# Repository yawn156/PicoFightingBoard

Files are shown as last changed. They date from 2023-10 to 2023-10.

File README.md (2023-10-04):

# Pico Fighting Board

Small fork of the OG Pico Fighting Board.

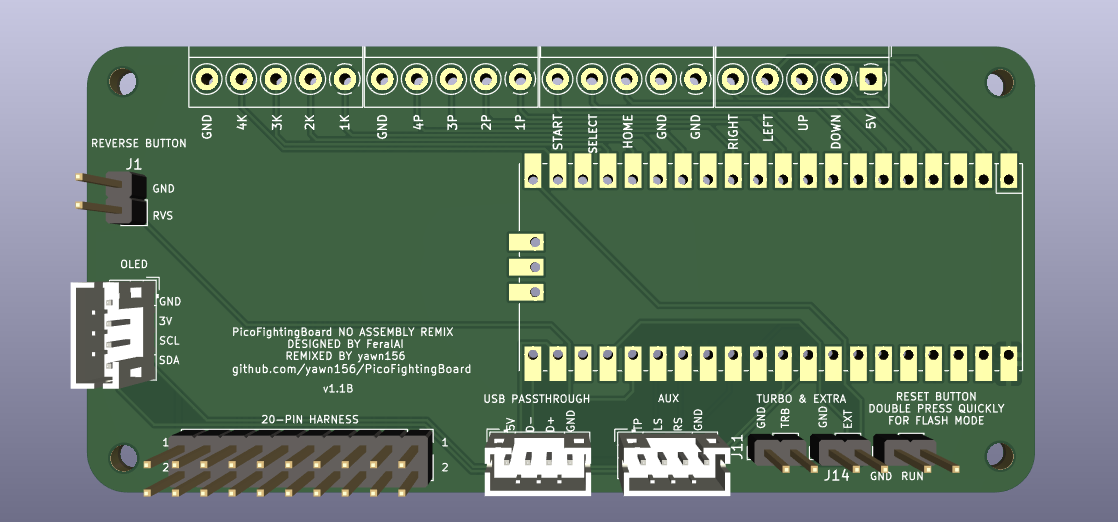
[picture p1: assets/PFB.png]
Pico Fighting Board v1.0


The idea behind this fork is for use with the [Open Stick](https://github.com/OpenStickCommunity/Hardware/tree/main/Fightstick%20Case) case, packing together less features than you would get from more advanced boards but also just enough to build a fightstick (with PS4/5 support with the new Passthrough addon).

Another important aspect about this fork is the focus on manual assembly to reduce costs and wait time for the big demand in common used parts from JLCPCB's assembly.

## List of Materials
- Raspberry pi Pico x1 
- JST PH 4Pin Male Terminal x3
- Screw Terminal 5Pin x4
- Male Pin header 10Pin x2
- Male pin header 2Pin x4

For wiring you'll either use the brook 20 pin connector or have a crimping tool with a bunch of 2.8mm female spade connectors.

## Firmware 
You'll want to use the PicoFightingBoard firmware from the [GP2040-CE](https://gp2040-ce.info/#/download) project.

The pins used for the connectors on the board are:
- USB Passthrough D+ = 21
- USB Passthrough D- = 22 (automatically set from the addon)
- Extra Button = 24
- Reverse button = 25
- TP = 26 *
- LS = 27 *
- RS = 29 *
- SDA = 31 *
- SCL = 32 *

(Pins marked with * may be already set in the webconfigurator.)

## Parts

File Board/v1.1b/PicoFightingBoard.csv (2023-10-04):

Comment | Designator | Footprint | LCSC
0.1uF | C1 | Capacitor_SMD:C_0805_2012Metric
MountingHole | H1,H2,H3,H4 | MountingHole:MountingHole_2.7mm_M2.5
Conn_01x02_Male | J10 | Connector_PinHeader_2.54mm:PinHeader_1x02_P2.54mm_Vertical
Conn_02x10_Odd_Even | J2 | Connector_PinHeader_2.54mm:PinHeader_2x10_P2.54mm_Vertical
Conn_01x05_Male | J3 | Connector_JST:JST_PH_B5B-PH-K_1x05_P2.00mm_Vertical
Conn_01x04_Male | J1,J4,J11,J12 | Connector_JST:JST_PH_B4B-PH-K_1x04_P2.00mm_Vertical
ST01x05 | J5,J6,J7,J8 | TerminalBlock_MetzConnect:TerminalBlock_MetzConnect_Type059_RT06305HBWC_1x05_P3.50mm_Horizontal
Conn_01x04_Male | J9,J13 | FeralAI:BOOM_SH_C145961_1x04_P1.00mm_Vertical
330 | R1,R2,R3,R4,R5 | Resistor_SMD:R_0805_2012Metric
4.7k | R6,R7 | Resistor_SMD:R_0805_2012Metric
Pico | U1 | MCU_RaspberryPi_and_Boards:RPi_Pico_SMD_TH_Clean
SN74LV1T34DBV | U2 | Package_TO_SOT_SMD:SOT-23-5

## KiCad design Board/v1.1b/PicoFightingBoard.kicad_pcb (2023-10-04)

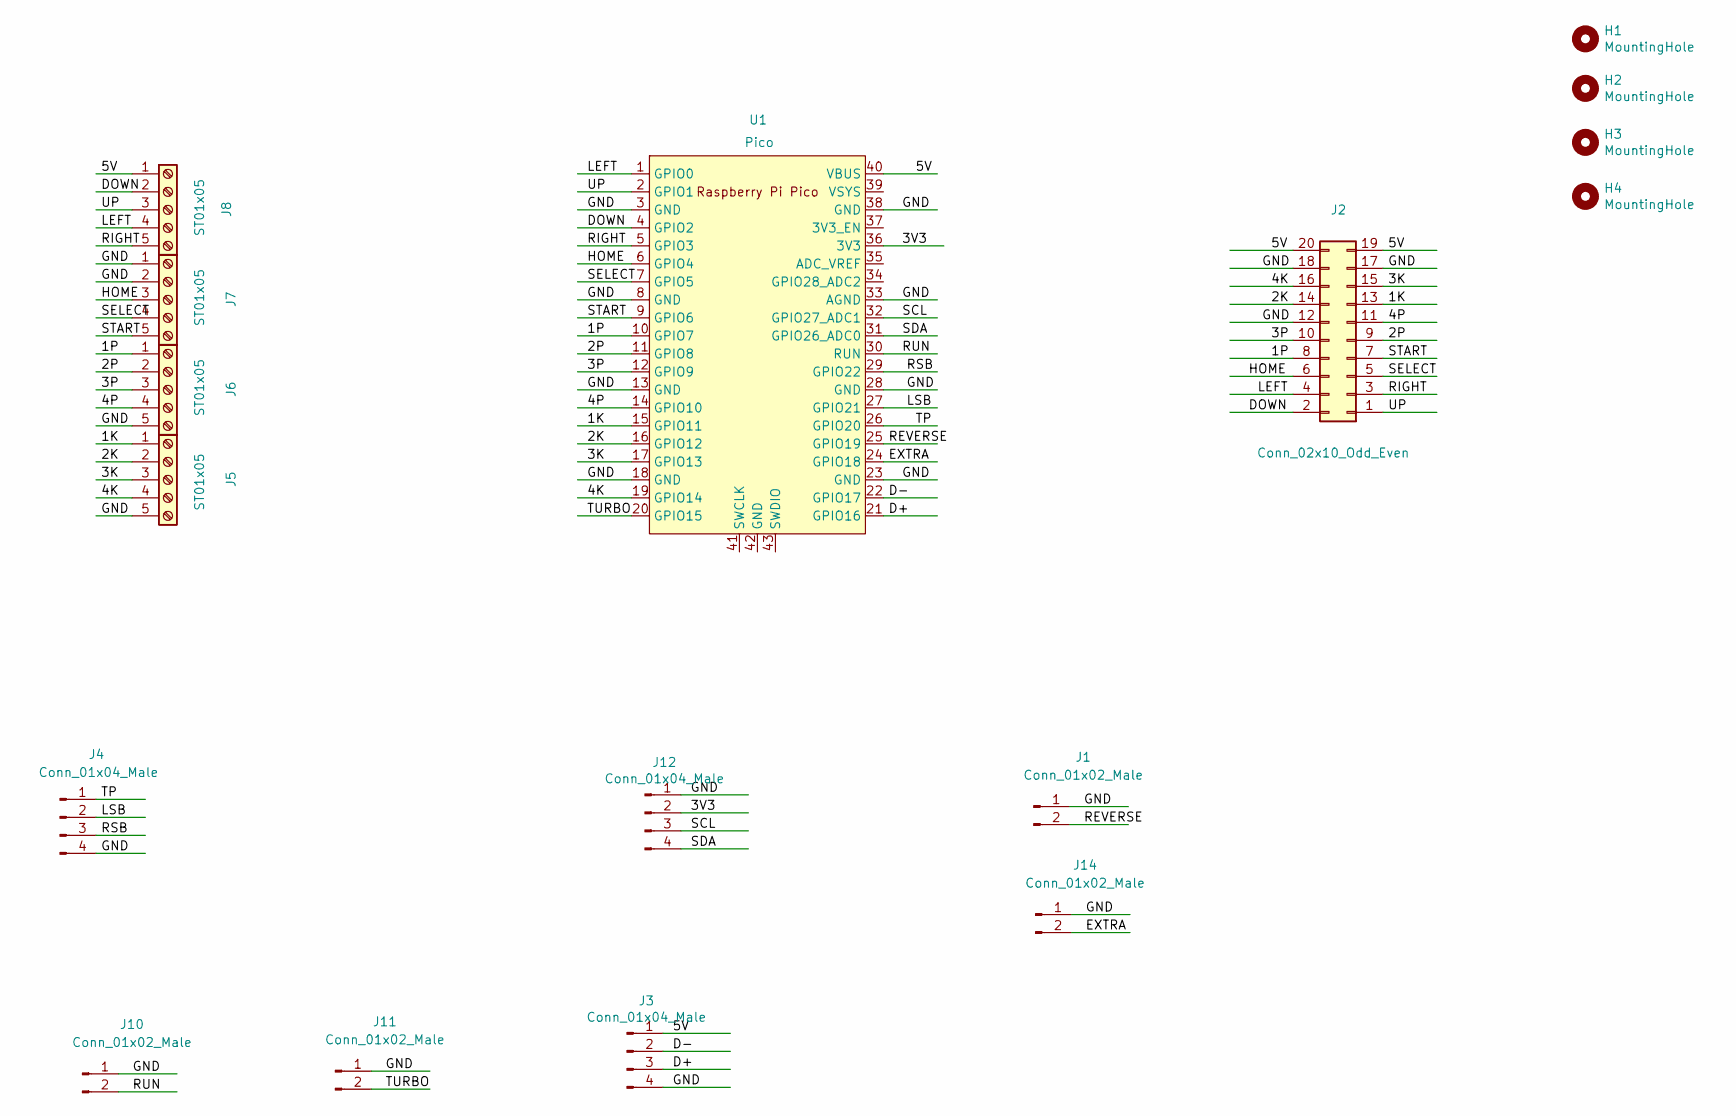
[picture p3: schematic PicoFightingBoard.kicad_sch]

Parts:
H1, H2, H3, H4: MountingHole; MountingHole_2.7mm_M2.5
J1, J10, J11, J14: Conn_01x02_Male; PinHeader_1x02_P2.54mm_Vertical
J2: Conn_02x10_Odd_Even; PinHeader_2x10_P2.54mm_Vertical
J3, J4, J12: Conn_01x04_Male; JST_PH_B4B-PH-K_1x04_P2.00mm_Vertical
J5, J6, J7, J8: ST01x05; TerminalBlock_MetzConnect_Type059_RT06305HBWC_1x05_P3.50mm_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
U1: Pico; RPi_Pico_SMD_TH_Clean

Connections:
/1K: J2.13, J5.1, U1.15 (GPIO11)
/1P: J2.8, J6.1, U1.10 (GPIO7)
/2K: J2.14, J5.2, U1.16 (GPIO12)
/2P: J2.9, J6.2, U1.11 (GPIO8)
/3K: J2.15, J5.3, U1.17 (GPIO13)
/3P: J2.10, J6.3, U1.12 (GPIO9)
/3V3: J12.2, U1.36 (3V3)
/4K: J2.16, J5.4, U1.19 (GPIO14)
/4P: J2.11, J6.4, U1.14 (GPIO10)
/5V: J2.19, J2.20, J3.1, J8.1, U1.40 (VBUS)
/D+: J3.3, U1.21 (GPIO16)
/D-: J3.2, U1.22 (GPIO17)
/DOWN: J2.2, J8.2, U1.4 (GPIO2)
/EXTRA: J14.2, U1.24 (GPIO18)
/GND: J1.1, J2.12, J2.17, J2.18, J3.4, J4.4, J5.5, J6.5, J7.1, J7.2, J10.1, J11.1, J12.1, J14.1, U1.3 (GND), U1.8 (GND), U1.13 (GND), U1.18 (GND), U1.23 (GND), U1.28 (GND), U1.33 (AGND), U1.38 (GND)
/HOME: J2.6, J7.3, U1.6 (GPIO4)
/LEFT: J2.4, J8.4, U1.1 (GPIO0)
/LSB: J4.2, U1.27 (GPIO21)
/REVERSE: J1.2, U1.25 (GPIO19)
/RIGHT: J2.3, J8.5, U1.5 (GPIO3)
/RSB: J4.3, U1.29 (GPIO22)
/RUN: J10.2, U1.30 (RUN)
/SCL: J12.3, U1.32 (GPIO27_ADC1)
/SDA: J12.4, U1.31 (GPIO26_ADC0)
/SELECT: J2.5, J7.4, U1.7 (GPIO5)
/START: J2.7, J7.5, U1.9 (GPIO6)
/TP: J4.1, U1.26 (GPIO20)
/TURBO: J11.2, U1.20 (GPIO15)
/UP: J2.1, J8.3, U1.2 (GPIO1)

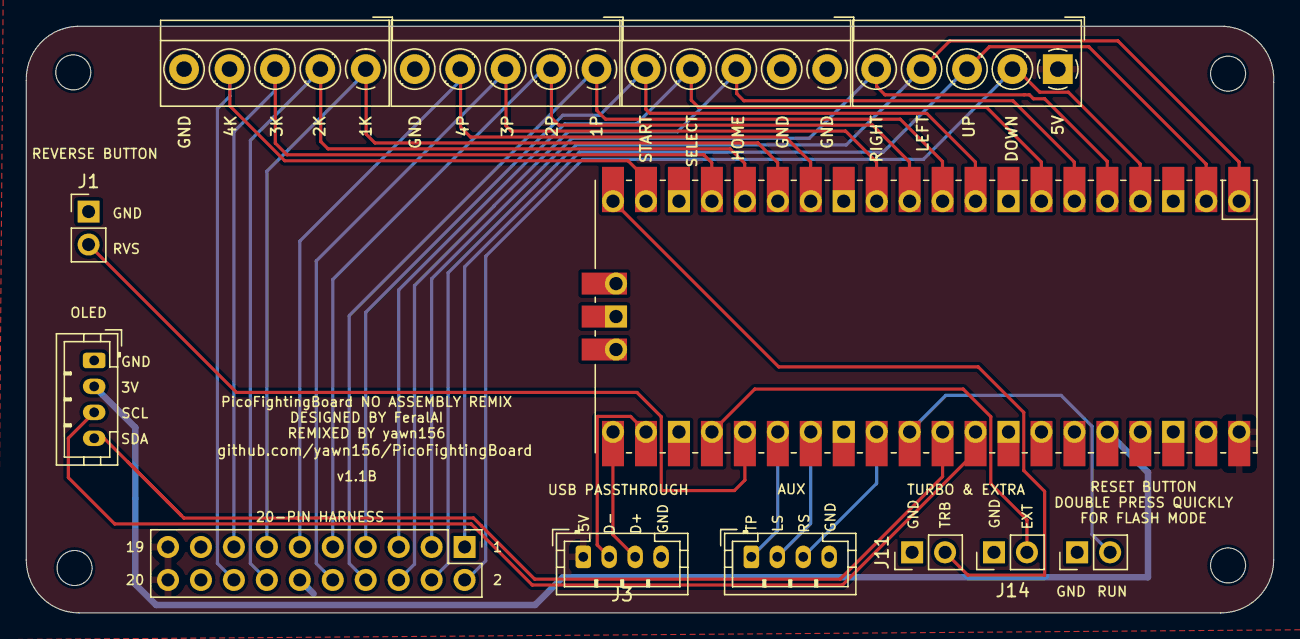
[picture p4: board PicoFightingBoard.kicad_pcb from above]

Board: 2 copper layers, 96.1 x 45.2 mm, 17 parts (0 on the bottom side), 29 nets.
